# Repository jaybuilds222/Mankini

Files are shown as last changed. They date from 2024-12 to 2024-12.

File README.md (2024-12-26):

A custom mechanical keyboard design based on FlatFootFox's take on a single-board version of Brian Low's Sofle Choc keyboard, which is itself a redesigned version of the Sofle keyboard by Josef Adamčík. It uses MrZealot's excellent Ergogen engine to layout the design.

I've made two versions so far. One is designed to use Kailh V1 Choc low-profile keyswitches. The other is designed for Cherry MX switches.

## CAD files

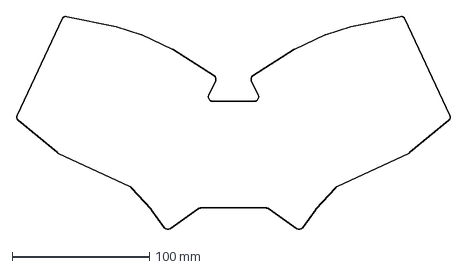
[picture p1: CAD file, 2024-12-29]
MX/basic.dxf
316.1 x 155.6 mm

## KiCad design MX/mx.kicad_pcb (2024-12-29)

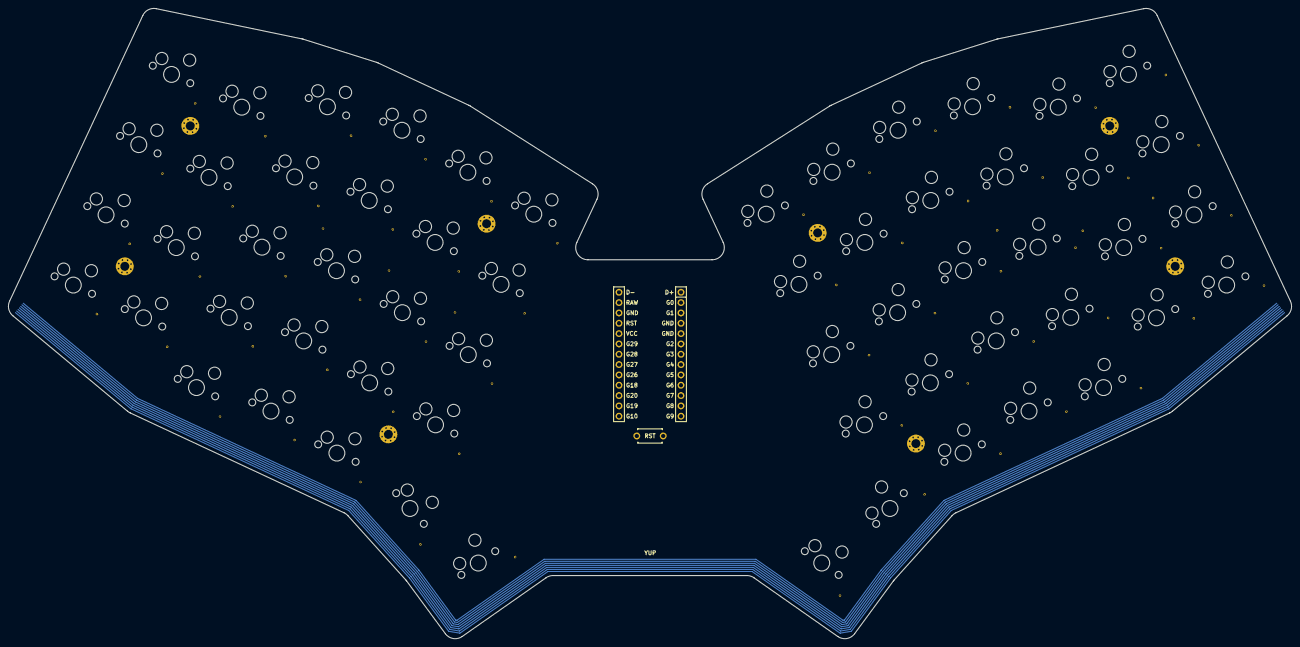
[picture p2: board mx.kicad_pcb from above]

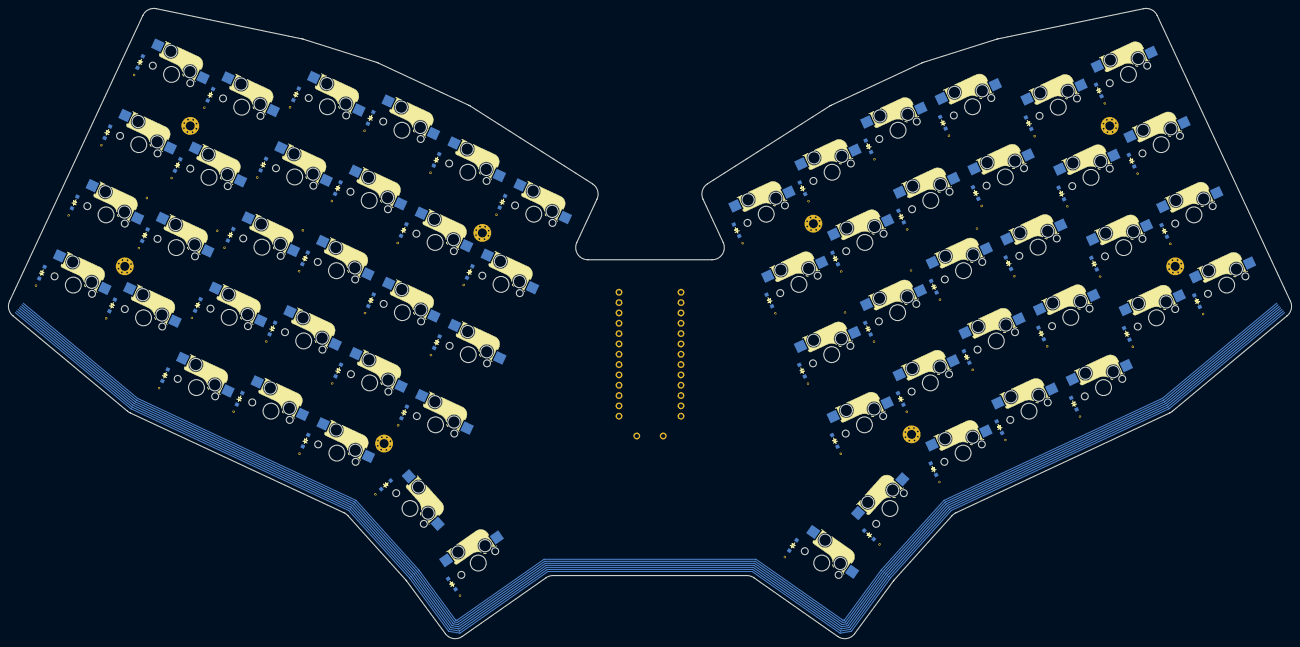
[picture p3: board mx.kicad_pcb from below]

Board: 2 copper layers, 315.5 x 155.0 mm, 126 parts (116 on the bottom side), 76 nets, no tracks yet.

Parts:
D1, D2, D3, D4, D5, D6, D7, D8, D9, D10, D11, D12, D13, D14, D15, D16, D17, D18, D19, D20, D21, D22, D23, D24, D25, D26, D27, D28, D29, D30, D31, D32, D33, D34, D35, D36, D37, D38, D39, D40, D41, D42, D43, D44, D45, D46, D47, D48, D49, D50, D51, D52, D53, D54, D55, D56, D57, D58: diode_tht_sod123
MCU1: mcu_rp2040
RST1: reset_switch_tht_top
S1, S2, S3, S4, S5, S6, S7, S8, S9, S10, S11, S12, S13, S14, S15, S16, S17, S18, S19, S20, S21, S22, S23, S24, S25, S26, S27, S28, S29, S30, S31, S32, S33, S34, S35, S36, S37, S38, S39, S40, S41, S42, S43, S44, S45, S46, S47, S48, S49, S50, S51, S52, S53, S54, S55, S56, S57, S58: switch_mx
_65, _66, _67, _68, _69, _70, _71, _72: MountingHole_2.2mm_M2_Pad_Via

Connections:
G2: D33.1, D37.1, D42.1, D47.1, D52.1, D56.1, MCU1.6
G3: D32.1, D36.1, D41.1, D46.1, D51.1, D55.1, MCU1.7
G4: MCU1.8, S1.1, S2.1, S3.1, S4.1, S30.1, S31.1, S32.1, S33.1
G5: MCU1.9, S5.1, S6.1, S7.1, S8.1, S9.1, S34.1, S35.1, S36.1, S37.1, S38.1
G6: MCU1.10, S10.1, S11.1, S12.1, S13.1, S14.1, S39.1, S40.1, S41.1, S42.1, S43.1
G7: D31.1, D35.1, D40.1, D45.1, D50.1, D54.1, MCU1.11
G8: D30.1, D34.1, D39.1, D44.1, D49.1, D53.1, MCU1.12
G9: D38.1, D43.1, D48.1, D57.1, D58.1, MCU1.13
G10: D9.1, D14.1, D19.1, D28.1, D29.1, MCU1.14
G18: MCU1.17, S24.1, S25.1, S26.1, S27.1, S29.1, S53.1, S54.1, S55.1, S56.1, S58.1
G19: D1.1, D5.1, D10.1, D15.1, D20.1, D24.1, MCU1.15
G20: D2.1, D6.1, D11.1, D16.1, D21.1, D25.1, MCU1.16
G26: MCU1.18, S20.1, S21.1, S22.1, S23.1, S28.1, S49.1, S50.1, S51.1, S52.1, S57.1
G27: MCU1.19, S15.1, S16.1, S17.1, S18.1, S19.1, S44.1, S45.1, S46.1, S47.1, S48.1
G28: D3.1, D7.1, D12.1, D17.1, D22.1, D26.1, MCU1.20
G29: D4.1, D8.1, D13.1, D18.1, D23.1, D27.1, MCU1.21
GND: MCU1.4, MCU1.5, MCU1.24, RST1.2
RST: MCU1.23, RST1.1
index_bottom: D20.2, S20.2
index_home: D21.2, S21.2
index_mod: D19.2, S19.2
index_num: D23.2, S23.2
index_top: D22.2, S22.2
inner_bottom: D24.2, S24.2
inner_home: D25.2, S25.2
inner_num: D27.2, S27.2
inner_top: D26.2, S26.2
middle_bottom: D15.2, S15.2
middle_home: D16.2, S16.2
middle_mod: D14.2, S14.2
middle_num: D18.2, S18.2
middle_top: D17.2, S17.2
mirror_index_bottom: D49.2, S49.2
mirror_index_home: D50.2, S50.2
mirror_index_mod: D48.2, S48.2
mirror_index_num: D52.2, S52.2
mirror_index_top: D51.2, S51.2
mirror_inner_bottom: D53.2, S53.2
mirror_inner_home: D54.2, S54.2
mirror_inner_num: D56.2, S56.2
mirror_inner_top: D55.2, S55.2
mirror_middle_bottom: D44.2, S44.2
mirror_middle_home: D45.2, S45.2
mirror_middle_mod: D43.2, S43.2
mirror_middle_num: D47.2, S47.2
mirror_middle_top: D46.2, S46.2
mirror_outer_bottom: D30.2, S30.2
mirror_outer_home: D31.2, S31.2
mirror_outer_num: D33.2, S33.2
mirror_outer_top: D32.2, S32.2
mirror_pinky_bottom: D34.2, S34.2
mirror_pinky_home: D35.2, S35.2
mirror_pinky_num: D37.2, S37.2
mirror_pinky_top: D36.2, S36.2
mirror_ring_bottom: D39.2, S39.2
mirror_ring_home: D40.2, S40.2
mirror_ring_mod: D38.2, S38.2
mirror_ring_num: D42.2, S42.2
mirror_ring_top: D41.2, S41.2
mirror_select_fan: D57.2, S57.2
mirror_space_fan: D58.2, S58.2
outer_bottom: D1.2, S1.2
outer_home: D2.2, S2.2
outer_num: D4.2, S4.2
outer_top: D3.2, S3.2
pinky_bottom: D5.2, S5.2
pinky_home: D6.2, S6.2
pinky_num: D8.2, S8.2
pinky_top: D7.2, S7.2
ring_bottom: D10.2, S10.2
ring_home: D11.2, S11.2
ring_mod: D9.2, S9.2
ring_num: D13.2, S13.2
ring_top: D12.2, S12.2
select_fan: D28.2, S28.2
space_fan: D29.2, S29.2

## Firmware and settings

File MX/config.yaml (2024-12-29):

meta:
  engine: 4.1.0
units:
  Mx: 14  #mounting hole width
  My: 14  #mountign hole height
  Sx: U   #X spacing
  Sy: U   #Y spacing
  Kx: Sx-1.05  #keycap width
  Ky: Sy-1.05  #Keycap height
  Pb: 3   #PCB buffer
  bx: 0.5Sx + Pb
  by: 0.5Sy + Pb

points:
  zones:
    matrix:
      anchor:
        shift: [0, 0]
        # shift: [122, -100]
      key:
        spread: Sx
        padding: Sy
        width: Kx
        height: Ky
      columns:
        outer:
          key:
            col_net: G4
          rows:
            mod.skip: true
        pinky:
          key:
            col_net: G5
          rows:
            mod.skip: true
        ring:
          key:
            stagger: 9
            col_net: G6
          rows:
            mod.col_net: G5
        middle:
          key:
            stagger: 2.5
            col_net: G27
          rows:
            mod.col_net: G6
        index:
          key:
            stagger: -2.5
            col_net: G26
          rows:
            mod.col_net: G27
        inner:
          key:
            stagger: -2.5
            col_net: G18
          rows:
            mod.skip: true
      rows:
        mod:
          row_net: G10
          mirror.row_net: G9
        bottom:
          row_net: G19
          mirror.row_net: G8
        home:
          row_net: G20
          mirror.row_net: G7
        top:
          row_net: G28
          mirror.row_net: G3
        num:
          row_net: G29
          mirror.row_net: G2
    thumbfan:
      anchor:
        ref: matrix_inner_mod
        shift: [3, -2.25]
      key:
        spread: Sx
        padding: Sy
        width: Kx
        height: Ky
      columns:
        select:
          key:
            splay: -23
            col_net: G26
        space:
          key:
            spread: 21.2
            stagger: 3.5
            splay: 83
            width: 1.5Kx
            col_net: G18
      rows:
        fan:
          row_net: G10
          mirror.row_net: G9
  rotate: -25
  mirror:
    ref: matrix_inner_num
    distance: 3U

outlines:
  keys:
    - what: rectangle
      where: true
      asym: both
      size: [Kx, Ky]
    - what: rectangle
      where: thumbfan_space_fan
      asym: both
      size: [1.5Kx, Ky]
  key_holes:
    - what: rectangle
      where: true
      size: [Mx, My]
  basic:
    - what: polygon
      operation: stack
      points:
        - ref: matrix_outer_num
          shift: [-bx, by]
        - ref: matrix_outer_bottom
          shift: [-bx, -by]
        - ref: matrix_ring_mod
          shift: [-bx, -by]
        - ref: thumbfan_select_fan
          shift: [-bx+3, -by]
        - ref: thumbfan_select_fan
          shift: [bx, -by]
        - ref: thumbfan_space_fan
          shift: [-bx-4, -by]
        - ref: thumbfan_space_fan
          shift: [bx, -by]
        - ref: mirror_thumbfan_space_fan
          shift: [bx, -by]
        - ref: mirror_thumbfan_space_fan
          shift: [-bx-4, -by]
        - ref: mirror_thumbfan_select_fan
          shift: [bx, -by]
        - ref: mirror_thumbfan_select_fan
          shift: [-bx+3,-by]
        - ref: mirror_matrix_ring_mod
          shift: [-bx, -by]       
        - ref: mirror_matrix_outer_bottom
          shift: [-bx, -by]          
        - ref: mirror_matrix_outer_num
          shift: [-bx, by]
        - ref: mirror_matrix_ring_num
          shift: [-bx, by]   
        - ref: mirror_matrix_middle_num
          shift: [-bx, by]                    
        - ref: mirror_matrix_middle_num
          shift: [bx, by]
        - ref: mirror_matrix_inner_num
          shift: [bx, by]
        - ref: mirror_matrix_inner_top
          shift: [bx, by]
        - ref: matrix_inner_top
          shift: [bx, by]
        - ref: matrix_inner_num
          shift: [bx, by]
        - ref: matrix_middle_num
          shift: [bx, by]
        - ref: matrix_middle_num
          shift: [-bx, by]
        - ref: matrix_ring_num
          shift: [-bx, by]
      fillet: 3
  preview:
    - what: outline
      name: basic
    - what: outline
      name: keys
      operation: stack
  mounting_plate:
    - what: outline
      name: basic
    - what: outline
      name: key_holes
      operation: subtract
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
